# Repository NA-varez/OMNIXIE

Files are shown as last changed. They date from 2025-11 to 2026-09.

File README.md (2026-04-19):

# OMNIXIE
Nixie driver board to enable easy inclusion of a Nixie tube into projects. One common driver board to support a wide range of Nixie INdicator Tubes. I love modularity!

Initial sketches, ideas, original project intent was just a nixie clock. But I hated the feeling of desigingn a nixie clock with the nixie driver circuitry as single use for just a clock, when really you should be able to drive a nixie tube anywehere you'd like for displaying numbers. So that's where this inspiration came from

ALSO cnlohr's cnixxie. Particularly his MCU of choice ch32v003 and the accompanying library ch32v003fun and rv003usb inspired the digitally controlled flyback he uses in his design. Really in hopes of learning some skills he demonstrated in his youtube vide.

OMNIXIE is omni beause all of its OMNIXIE_HATs share a common hardware interface to the nixie driver board. Since nixie tubes wildly vary in their footprint, its nice to share a common hardware connection between them all thats what makes it omni. 

The real guts is the ddriver board.
Should be minimal in size such that it doesnt add any more difficult in creating some case for the nixie tube.
Should be relatively efficient like 90% efficiency on the flyback onverter
Should be programmable 
  There should be a software package that comes with the hardware that could easily spin up different functionality

The default program should allow the user of the board to immediatly get the devices to display a synchronized clock.
Via some qwiic connectors. Might have to be a custom i2c interface.

A flyback seemed to be the most suitable approach because of the smallest amount of parts needed for it.

WORK IN PROGRESS.

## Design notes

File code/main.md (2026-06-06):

//
// cnixi - ch32v003 base driver for IN-15 nixie tubes.
//
// Fully integrated PI flyback PSU controller + Nixie Tube output
// control with up to 2 channel simultaneous dimming.
//
// Copyright 2023 <>< Charles Lohr, under the MIT-X11 license or NewBSD
// license, you choose.
//
// Note: Before running this, you should run the optionbytes folder script
// in order configure RESET as a GPIO so you can use the AUX input as well
// as forcing the watchdog on by default. 
//

#define SYSTEM_CORE_CLOCK 48000000

#include "ch32v003fun.h"
#include <stdio.h>

static uint16_t GenOnMask( int segmenton );
static void ApplyOnMask( uint16_t onmask );
static inline void WatchdogPet();

// Limits the "ADC Set Value" in volts.
// This prevents us from exceeding 190 volts target.
#define ABSOLUTE_MAX_ADC_SET 190

// Do not mess with PWM_ values unless you know what you are willing to go down
// a very deep rabbit hole. I experimentally determined 140 for this particular
// system was on the more efficient side of things and gave good dynamic range.
// 140 means it's 48MHz / 140 = 342 kHz for the main flyback frequency.
//
// You can explore values by doing ENABLE_TUNING in here and in testnix.c
// #define ENABLE_TUNING
#ifndef ENABLE_TUNING
#define PWM_PERIOD 140
#else
int PWM_PERIOD = 140;
#endif
int pwm_max_duty = 48;  //This is changed based on vdd.

// Flyback PID loop Tuning Parameters
//
// This is a PID loop (you should read about this separately). But these terms
// are actually on the order of 2^term. So we are only able to get the tuning
// to a rough ballpark. Thankfully, PID loops are forgiving.
//
// Honestly, this is MUCH more sophisticated than it needs to be!  I was using
// a P-only loop for quite some time without any issues.
#define ERROR_P_TERM 2  // Actually 2^2
#define ERROR_D_TERM -1  // Actually 2^0
#define I_SAT_MAX (4096+2048) // SAT * 2^(-ADC_IIR+ERROR_I_TERM) = Max impact to PWM
#define I_SAT_MIN (-4096)
#define ERROR_I_TERM -5 // Actually 2^-6

// We filter our ADC inputs because they are kind of noisy.
//
// We can use Binary-shift IIR filters to filter the incoming ADC signals.
// See later in the code, but, it maps to only about 4 assembly instructions!
// (plus a read-back of the previous value we will be mixing).
#define ADC_IIR 2
#define VDD_IIR 2

// Target feedback, set by the user.
int target_feedback = 0;

// Feedback based on what the user set and the part's VDD.
int feedback_vdd = 0;

// Filtered ADC and VDD values.
int lastadc = 0;
int lastrefvdd = 0;

// Code for handling numeric fading, between 2 numbers or alone.

uint16_t fade_time0, fade_time1;
uint16_t fade_disp0, fade_disp1;

static uint32_t HandleFade( uint8_t fadepos )  __attribute__((section(".srodata")));
static uint32_t HandleFade( uint8_t fadepos )
{
	// Digit fade.  Use fade_timeX and fade_dispX to handle fade logic.
	if( fadepos < fade_time0 )
		return fade_disp0;
	else if( fadepos < fade_time1 ) 
		return fade_disp1;
	else
		return 0;
}

static inline uint32_t FastMultiply( uint32_t big_num, uint32_t small_num );
static inline uint32_t FastMultiply( uint32_t big_num, uint32_t small_num )
{
	// The CH32V003 is an EC core, so no hardware multiply. GCC's way multiply
	// is slow, so I wrote this.
	//
	// This basically does this:
	//	return small_num * big_num;
	//
	// Note: This does NOT check for zero to begin with, though this still
	// produces the correct results, it is a little weird that even if
	// small_num is zero it executes once.
	//
	// Additionally note, instead of the if( m&1 ) you can do the following:
	//  ret += multiplciant & neg(multiplicand & 1).
	//
	// BUT! Shockingly! That is slower than an extra branch! The CH32V003
	//  can branch unbelievably fast.
	//
	// This is functionally equivelent and much faster.
	//
	// Perf numbers, with small_num set to 180V.
	//  No multiply:         21.3% CPU Usage
	//  Assembly below:      42.4% CPU Usage  (1608 bytes for whole program)
	//  C version:           41.4% CPU Usage  (1600 bytes for whole program)
	//  Using GCC (__mulsi3) 65.4% CPU Usage  (1652 bytes for whole program)
	//
	// The multiply can be done manually:
	uint32_t ret = 0;
	uint32_t multiplicand = small_num;
	uint32_t mutliplicant = big_num;
	do
	{
		if( multiplicand & 1 )
			ret += mutliplicant;
		mutliplicant<<=1;
		multiplicand>>=1;
	} while( multiplicand );
	return ret;

	// Which is equivelent to the following assembly (If you were curious)
/*
	uint32_t ret = 0;
	asm volatile( "\n\
		.option   rvc;\n\
	1:	andi t0, %[small], 1\n\
		beqz t0, 2f\n\
		add %[ret], %[ret], %[big]\n\
	2:	srli %[small], %[small], 1\n\
		slli %[big], %[big], 1\n\
		bnez %[small], 1b\n\
	" :
		[ret]"=&r"(ret), [big]"+&r"(big_num), [small]"+&r"(small_num) : :
		"t0" );
	return ret;
*/
}

// FYI You can use functions in ram to make them work faster.  The .srodata
// attribute. This means this function gets placed into RAM. Normally this
// function takes approximately 2.5-3us to execute from flash, but only 2-2.5us
// to execute from RAM.

// This is an interrupt called by an ADC conversion.
void ADC1_IRQHandler(void)
	__attribute__((interrupt))
	__attribute__((section(".srodata")));

void ADC1_IRQHandler(void)
{
	// If you want to see how long this functon takes to run, you can use a
	// scope and then monitor pin D6 if you uncomment this and the bottom copy.
	GPIOD->BSHR = 1<<6;

	// Acknowledge pending interrupts.
	// This will always be ADC_JEOC, so we don't need to check.
	ADC1->STATR = 0;

	// Acknowledge the interrupt.
	
	// It is crucial that our ADC sample is ALWAYS ALIGNED to the PWM, that way
	// any ripple and craziness that happens from the chopping of the flyback
	// is completely filtered out because of where we are sampling.

	// This performs a low-pass filter on our data, ADC1->RDATAR the sample
	// rate, always.  As a side note, the value of the IIR (but now it's
	// 2^VDD_IIR bigger)

	int adcraw = ADC1->RDATAR;
	int newadc = adcraw + (lastadc - (lastadc>>ADC_IIR));
	lastadc = newadc;

	int err = feedback_vdd - lastadc;

	static int integral;
	static int lasterr;
	int derivative = (err - lasterr);
	lasterr = err;
	integral += err;

	// We asymmetrically allow the integral to saturate, to help prevent long-
	// term oscillations.
	integral = ( integral > ((I_SAT_MAX)<<ADC_IIR) ) ? ((I_SAT_MAX)<<ADC_IIR) : integral;
	integral = ( integral < ((I_SAT_MIN)<<ADC_IIR) ) ? ((I_SAT_MIN)<<ADC_IIR) : integral;

	// This is the heart of the PID loop.
	// General note about shifting: Be sure to combine your shifts.
	// If you shift right, then left, you will lose bits of precision.
	// These shifts turn into single left and right immediate shifts.
	int plant = 
		(err << ( (-ADC_IIR) + (ERROR_P_TERM) )) +
		(integral >> ( ADC_IIR - (ERROR_I_TERM) )) +
		(derivative >> ( (ADC_IIR) - (ERROR_D_TERM) ) );
	plant = ( plant > pwm_max_duty ) ? pwm_max_duty : plant;
	plant = ( plant < 0 ) ? 0 : plant;
	TIM1->CH2CVR = plant;

	// Use injection channel data to read vref.  This is needed because we
	// measure all values WRT to VDD and GND.  So we need to measure the vref
	// a lot to make sure we know what value we are are targeting Ballparks
	//   (for unfiltered numbers)  (Just as a note)
	//   0xF0  / 240 for 5V input << lastrefvdd
	//	 0x175 / 373 for 3.3v input << lastrefvdd

	// Do an IIR low-pass filter on VDD. See IIR discussion above.
	uint32_t vdd = lastrefvdd = ADC1->IDATAR1 + (lastrefvdd - (lastrefvdd>>VDD_IIR));

#ifndef ENABLE_TUNING

	// If we aren't enabling tuning, we can update max on time here. We want to
	// limit on-time based on DC voltage on the flyback so that we can get
	// close to (But not get into) saturation of the flyback transformer's core
	//
	// We can compute expected values, but experimenting is better.
	// Transformer inductance is ~6uH.
	// Our peak current is ~500mA
	// The average voltage is ~4V
	//
	//   4V / .000006H = 0.5A / 666666A/s = 750nS but turns out this was
	//    pessemistic.
	//
	// Experimentation showed that the core of the transformer saturates in
	// about 1uS at 5V and 1.4uS at 3.3v.  More specifically the relationhip
	// between our maximum on-time and vref-measured-by-vdd works out to about:
	//
	//    max_on_time_slices = lastrefvdd / 4.44.
	//
	// There's a neat trick where you can divide by weird decimal divisors by
	// adding and subtracing terms. We perform this trick here and below
	//
	// 1÷(1÷4−1÷64−1÷128−1÷1024) is about equal to dividing by 4.43290
	//  It can be simplified it for our purposes as: 1÷(1÷4−1÷64−1÷128)
	//
	// You can arbitrarily add and subtract terms to get as closed to your
	// desired target value as possbile.
	//
	// When we divide a value by powers-of-two, it becomes a bit shift.
	//
	// The bit shift and IIR adjustments can be made so that the compiler can
	// optimize out the addition there.
	//
	// The following code actually
	pwm_max_duty = 
		  (lastrefvdd>>(2+VDD_IIR)) 
		- (lastrefvdd>>(6+VDD_IIR))
		- (lastrefvdd>>(7+VDD_IIR));
#endif

	// target_feedback is in volts. 0..200 maps to the device voltage.
	// lastrefvdd = 0xF0  for 5V input.
	// lastrefvdd = 0x175 for 3.3v input.
	//
	// feedback_vdd = 408 for ~192V @ 5
	// feedback_vdd = 680 for ~192V @ 3.3
	//
	// 408 = 192 * 240 / x = (192*240)/408 = 112.941176471
	// 680 = 192 * 373 / x = (373*680)/192 = 105.317647059
	//
	//  More tests showed this value across units is around 120.
	//
	// X This becomes our denominator.
	// feedback_vdd = (current vdd measurement * target voltage) / 120
	// 
	// Further testing identified that the denominator is almost exactly 120.
	// We can perform a divison by 120 very quickly by
	//
	//   feedback = numerator/128 + numerator/2048
	//
	// See note above about the constant division trick.
	//
	// Side-note:
	//
	// This is unintuitively slow becuase is because it uses a multiply. The
	// CH32V003 does not natively have a multiply instruction, If you use a *
	// it calls out to __mulsi3 in libgcc.a. 

	// The following line of code is still *more* than fast enough but, to
	// write it out manually, we can get even faster!
	//
	//	uint32_t numerator = (vdd * target_feedback);

	uint32_t numerator = FastMultiply( vdd, target_feedback );

	feedback_vdd =
		(numerator>>(7+VDD_IIR-ADC_IIR)) +
		(numerator>>(11+VDD_IIR-ADC_IIR));

	// Pet the watchdog.  If we got here, things should be OK.
	WatchdogPet();

	GPIOD->BSHR = (1<<(16+6));
}

static void SetupTimer1()
{
	// Enable Timer 1
	RCC->APB2PRSTR |= RCC_APB2Periph_TIM1;
	RCC->APB2PRSTR &= ~RCC_APB2Periph_TIM1;

	TIM1->PSC = 0x0000;  // Prescalar to 0x0000 (so, 48MHz base clock)
	TIM1->ATRLR = PWM_PERIOD;
	TIM1->CCER = TIM_CC2E | TIM_CC2NP;  // CH2 is control for FET.
	TIM1->CHCTLR1 = TIM_OC2M_2 | TIM_OC2M_1;

	TIM1->CH2CVR = 0;  // Actual duty cycle (Off to begin with)

	// Setup TRGO for ADC.  This makes is to the ADC will trigger on timer
	// reset, so we trigger at the same position every time relative to the
	// FET turning on.
	TIM1->CTLR2 = TIM_MMS_1;

	// Enable TIM1 outputs
	TIM1->BDTR = TIM_MOE;
	TIM1->CTLR1 = TIM_CEN;
}

static void SetupTimer2()
{
	// Enable Timer 2
	RCC->APB1PRSTR |= RCC_APB1Periph_TIM2;
	RCC->APB1PRSTR &= ~RCC_APB1Periph_TIM2;

	// PD7 will be used as Timer 2, Channel 4 Configure timer 2 to enable this.
	//TIM2->SWEVGR = 0x0001; 			//TIM_PSCReloadMode_Immediate;

	TIM2->PSC = 0x0020;
	TIM2->ATRLR = 255;				// 0..255 (So we can be 100% on)
	TIM2->CHCTLR2 = TIM_OC4M_2 | TIM_OC4M_1;
	TIM2->CCER = TIM_CC4E;
	TIM2->CH4CVR = 0;  			// Actual duty cycle (Off to begin with)

	// Enable TIM1 outputs
	TIM2->BDTR = TIM_MOE;
	TIM2->CTLR1 = TIM_CEN;
}

static void SetupADC()
{
	// Configure ADC.
	// PD4 is analog input chl 7
	GPIOD->CFGLR &= ~(0xf<<(4*4));	// CNF = 00: Analog, MODE = 00: Input
	
	// Reset the ADC to init all regs
	RCC->APB2PRSTR |= RCC_APB2Periph_ADC1;
	RCC->APB2PRSTR &= ~RCC_APB2Periph_ADC1;

	// ADCCLK = 12 MHz => RCC_ADCPRE divide by 4
	RCC->CFGR0 &= ~RCC_ADCPRE;  // Clear out the bis in case they were set
	RCC->CFGR0 |= RCC_ADCPRE_DIV4;	// set it to 010xx for /4.

	// Set up single conversion on chl 7
	ADC1->RSQR1 = 0;
	ADC1->RSQR2 = 0;
	ADC1->RSQR3 = 7;	// 0-9 for 8 ext inputs and two internals
	
	//Injection group is 8. NOTE: See note in 9.3.12 (ADC_ISQR) of TRM. The
	// group numbers is actually 4-group numbers.
	ADC1->ISQR = (8<<15) | (0<<20);

	// Sampling time for channels. Careful: This has PID tuning implications.
	// Note that with 3 and 3,the full loop (and injection) runs at 138kHz.
	ADC1->SAMPTR2 = (3<<(3*7)) | (3<<(3*8)); 
		// 0:7 => 3/9/15/30/43/57/73/241 cycles
		// (4 == 43 cycles), (6 = 73 cycles)  Note these are alrady /2, so 
		// setting this to 73 cycles actually makes it wait 256 total cycles
		// @ 48MHz.

	// Turn on ADC and set rule group to sw trig
	// 0 = Use TRGO event for Timer 1 to fire ADC rule.
	ADC1->CTLR2 = ADC_ADON | ADC_JEXTTRIG | ADC_JEXTSEL | ADC_EXTTRIG; 

	// Reset calibration
	ADC1->CTLR2 |= ADC_RSTCAL;
	while(ADC1->CTLR2 & ADC_RSTCAL);

	// Calibrate ADC
	ADC1->CTLR2 |= ADC_CAL;
	while(ADC1->CTLR2 & ADC_CAL);

	// enable the ADC Conversion Complete IRQ
	NVIC_EnableIRQ( ADC_IRQn );

	// ADC_JEOCIE: Enable the End-of-conversion interrupt.
	// ADC_JDISCEN | ADC_JAUTO: Force injection after rule conversion.
	// ADC_SCAN: Allow scanning.
	ADC1->CTLR1 = ADC_JEOCIE | ADC_JDISCEN | ADC_SCAN | ADC_JAUTO;
}

// Apply a given output mask to the GPIO ports the nixie tubes are hooked into.
static void ApplyOnMask( uint16_t onmask )
{
	GPIOD->OUTDR = (onmask >> 8) | 0x80;
	GPIOC->OUTDR = onmask & 0xff;
}

uint16_t GenOnMask( int segmenton )
{
	// Produce a bit mask with only one bit on. To indicate the IO to turn on
	// to light up a given segment.  If segmenton == 0, then all IO are off.
	if( segmenton > 0 )
	{
		segmenton--;
		if( segmenton < 8 )
			return 1<<segmenton;
		else if( segmenton == 8 )
			return (1<<2)<<8;
		else if( segmenton == 9 )
			return (1<<3)<<8;
		else if( segmenton == 10 )
			return (1<<0)<<8;
		else if( segmenton == 11 )
			return (1<<7)<<8;
	}
	return 0;
}

static void HandleCommand( uint32_t dmdword )
{
	// You can use minichlink to setup this:
	// ./minichlink -s 0x04 0x00B40041 # Configure for 180V.
	// ./minichlink -s 0x04 0x00030042 # Light digit "8"
	// ./minichlink -s 0x04 0x60303243 # Dimly light 8 and 8.
	// ./minichlink -g 0x04            # Get status.

	// Note: To get here, DEBUG0's LSB must be 0x4x command is that 'x'
	int command = dmdword & 0x0f;

	switch( command )
	{
	case 1:
	{
		int feedback = dmdword >> 16;
		if( feedback > ABSOLUTE_MAX_ADC_SET )
			feedback = ABSOLUTE_MAX_ADC_SET;
		target_feedback = feedback;
		break;
	}
	case 2:
	{
		int segmenton = (dmdword>>16)&0x0f;

		fade_time0 = -1;
		fade_time1 = -1;
		fade_disp0 = GenOnMask(segmenton);
		fade_disp1 = 0;
		break;
	}
	case 3:
	{
		// Configure a fade.
		fade_disp0 = GenOnMask( ( dmdword >> 8 ) & 0xf );
		fade_disp1 = GenOnMask( ( dmdword >> 12 ) & 0xf );
		fade_time0 = ( dmdword >> 16 ) & 0xff;
		fade_time1 = ( dmdword >> 24 ) & 0xff;
		break;
	}
	case 4:
	{
#ifdef ENABLE_TUNING
		// this is only for tuning.
		if( ( dmdword & 0xff00 ) == 0xaa00 )
		{
			int period = (dmdword>>16)&0xff;
			if( period < 20 ) period = 20;
			PWM_PERIOD = period;
			TIM1->ATRLR = PWM_PERIOD;
			int max_duty = (dmdword>>24)&0xff;
			if( max_duty > period - 14 ) max_duty = period - 14;
			pwm_max_duty = max_duty;
		}
#endif
		break;
	}
	case 5:
	{
		// Aux Neon Control
		TIM2->CH4CVR = dmdword>>16;
	}

	}

	// Write the status back to the host PC.  Status is our VDD and our FB V
	*DMDATA0 = ((lastadc>>ADC_IIR) << 12) | ((lastrefvdd>>VDD_IIR) << 22);
}

static inline void WatchdogPet()
{
	// Writing 0xaaaa into the ctlr prevents the watchdog from killing us.
	IWDG->CTLR = 0xAAAA;
}

static inline void WatchdogSetup()
{
	// Setup watchdog.
	IWDG->CTLR = 0x5555; // Go into watchdog setup mode.
	while( IWDG->STATR & IWDG_PVU ); // Wait for PSCR to become recepitve.
	IWDG->PSCR = 1;      // div LSI by 8 (4 seems unreliable)
	IWDG->RLDR = 0xFFF;  // reload watchdog, not important don't need to check.
	IWDG->CTLR = 0xCCCC; // commit registers.
	WatchdogPet();
}

static inline void AdvanceFadePlace()
{
	static uint32_t lastmask = 0;

	// Causes us to cycle through all 256 sequence points every 1.5ms.
	uint32_t fadepos = (SysTick->CNT >> 5) & 0xff;

	// We want to glow the LEDs with a chopping period of less, so we
	// "rotate" the bits.  This has the effect of making the primary
	// switching frequency for the tubes much higher, but, at the same time
	// also jittering the edges in time so you can get a full 8-bit fade.
	// You can rotate more or less to control the periodicity.

	// With this scramble, the period scramble is about 93us.
	fadepos = (fadepos << 4) | ( fadepos >> 4);

	uint32_t mask = HandleFade( fadepos );
	if( mask != lastmask )
	{
		if( lastmask )
		{
			// Make sure we have a short gap with nothing on.
			ApplyOnMask( 0 );
			Delay_Us( 3 );
		}
		ApplyOnMask( mask );
		lastmask = mask;
	}
}

int main()
{
	// Configure a watchdog timer so if the chip goes crazy it will reset.
	WatchdogSetup();

	// Use internall RC oscillator + 2xPLL to generate 48 MHz system clock.
	SystemInit(); /// ********************************************

	// For the ability to printf() if we want.
	SetupDebugPrintf();

	// Pet watchdog for the rest of startup.
	WatchdogPet();

	// Enable Peripherals
	RCC->APB2PCENR |= RCC_APB2Periph_GPIOD | RCC_APB2Periph_GPIOC |
		RCC_APB2Periph_GPIOA | RCC_APB2Periph_TIM1 | RCC_APB2Periph_ADC1 |
		RCC_APB2Periph_AFIO;

	RCC->APB1PCENR = RCC_APB1Periph_TIM2;

	// I'm paranoid - let's make sure all tube cathodes are high-Z.
	ApplyOnMask( 0 );

	GPIOD->CFGLR = 
		(GPIO_Speed_10MHz | GPIO_CNF_OUT_PP)<<(4*6) | // GPIO D6 Debug
		(GPIO_Speed_10MHz | GPIO_CNF_OUT_PP_AF)<<(4*7) | // DIG_AUX  (TIM2CH4)
		(GPIO_Speed_10MHz | GPIO_CNF_OUT_PP)<<(4*3) | // DIG_9
		(GPIO_Speed_10MHz | GPIO_CNF_OUT_PP)<<(4*2) | // DIG_8
		(GPIO_Speed_10MHz | GPIO_CNF_IN_FLOATING)<<(4*1) | // PGM Floats.
		(GPIO_Speed_10MHz | GPIO_CNF_OUT_PP)<<(4*0);  // DIG_DOT

	GPIOC->CFGLR = 
		(GPIO_Speed_10MHz | GPIO_CNF_OUT_PP)<<(4*0) | // DIG_0
		(GPIO_Speed_10MHz | GPIO_CNF_OUT_PP)<<(4*1) | // DIG_1
		(GPIO_Speed_10MHz | GPIO_CNF_OUT_PP)<<(4*2) | // DIG_2
		(GPIO_Speed_10MHz | GPIO_CNF_OUT_PP)<<(4*3) | // DIG_3
		(GPIO_Speed_10MHz | GPIO_CNF_OUT_PP)<<(4*4) | // DIG_4
		(GPIO_Speed_10MHz | GPIO_CNF_OUT_PP)<<(4*5) | // DIG_5
		(GPIO_Speed_10MHz | GPIO_CNF_OUT_PP)<<(4*6) | // DIG_6
		(GPIO_Speed_10MHz | GPIO_CNF_OUT_PP)<<(4*7);  // DIG_7

	GPIOA->CFGLR =
		(GPIO_Speed_50MHz | GPIO_CNF_OUT_PP_AF)<<(4*1); //FLYBACK (T1CH2)

	SetupADC();
	SetupTimer1();
	SetupTimer2();

	*DMDATA0 = 0;

	target_feedback = 0;

	// Cause system timer to run and reload when it hits CMP and HCLK/8.
	// Also, don't stop at comparison value.
	SysTick->CTLR = 1;

	while(1)
	{
		uint32_t dmdword = *DMDATA0;
		if( (dmdword & 0xf0) == 0x40 )
		{
			// I think there is a compiler bug here.  For some reason if I put
			// the code in this function right here, it doesn't work right.
			// so I encapsulated the code in a function.
			//
			// This function handles commands we get over the programming
			// interface.  Like "set HV bus" or "set this digit on."
			HandleCommand( dmdword );
		}

		AdvanceFadePlace();

	}
}

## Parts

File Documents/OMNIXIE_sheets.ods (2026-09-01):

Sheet: PROTOTYPE BOM v0.1
 |  | BOM | 1 | OMNIXIE
 |  | SCH | 1
 |  | PCB | 1 | Designer: NA Design
 |  | DATE | 12/26/2025
PROCURED | TO BUY | Categories | Qty | MPN | Ref Des | Value | DNP | Description | Footprint/Package | Manufacturer | Distributor | Link
TRUE | TRUE | ICs/Modules | 1 | CH32V003F4U6 | U1 | - |  | QingKe V2 Microprocessor | Package_DFN_QFN:QFN-20-1EP_3x3mm_P0.4mm_EP1.65x1.65mm
TRUE | TRUE |  | 1 | PI4IOE5V6416ZDEX | U3 | - |  | I/O Expander 16 I2C 400 kHz 24-TQFN (4x4) | Package_DFN_QFN:TQFN-24-1EP_4x4mm_P0.5mm_EP2.1x2.1mm_ThermalVias
TRUE | TRUE |  | 1 | XC6206P332MR | U4 | - |  | IC REG LINEAR 3.3V 200MA SOT23 | Package_TO_SOT_SMD:SOT-23-3
TRUE | TRUE | Connections | 1 | USB4120-03-C | J4 | - |  | USB Connectors USB Type C,2.0, Rec,SMT, 0.95mmTH Shell Stakes,G/F,RA,Top Mnt,T&R
TRUE | FALSE |  | 2 | - | J1,J6 | - |  | 2.54mm Pitch Pin Headers
TRUE | TRUE |  | 7 | 5005 | TP6,TP8,TP10,TP11,TP12,TP13,TP14 | - |  | Test Plugs & Test Jacks TEST POINT RED .063 | TestPoint:TestPoint_Keystone_5005-5009_Compact
TRUE | TRUE |  | 1 | IL-WX-16S-VF-B-E1000E | J8 | - |  | 0.8 mm pitch, SMT, parallel/ vertical, Board-to-board Connector, 16 pos., Socket receptacle
TRUE | TRUE | Semiconductors | 1 | IPN50R1K4CEATMA1 | Q12 | - |  | MOSFETs CONSUMER | Package_TO_SOT_SMD:SOT-223-3_TabPin2
TRUE | TRUE |  | 12 | BSS123 | Q0,Q1,Q2,Q3,Q4,Q5,Q6,Q7,Q8,Q9,Q10,Q11 | - |  | MOSFET, N-CH, SINGLE, 0.19A, 100 | Package_TO_SOT_SMD:SOT-23-3
TRUE | TRUE |  | 1 | SK3200AFL-TP | D1 | - |  | Schottky Diodes & Rectifiers 3A 200Vr 140Vrms 200V 80A 0.86Vf | OMNIXIE:SK3200AFL
TRUE | TRUE |  | 2 | 150060GS73220 | D2, D3 | - |  | Green 525nm LED Indication - Discrete 3.2V 0603 (1608 Metric) | LED_SMD:LED_0603_1608Metric
TRUE | FALSE | Capacitors/Resistors | 1 | GRM21BR71A106MA73K | C1 | 10uF |  | Multilayer Ceramic Capacitors MLCC - SMD/SMT 10 uF 10 VDC 20% 0805 X7R | _0805
TRUE | TRUE |  | 1 | GRM43DR7LV224KW01L | C2 | 0.22uF |  | Multilayer Ceramic Capacitors MLCC - SMD/SMT 0.22 uF 630 VDC 10% 1812 X7R | 1210
TRUE | FALSE |  | 3 | CL10B105KA8NFNC | C3, C4, C5 | 1uF |  | 1 µF ±10% 25V Ceramic Capacitor X7R 0603 (1608 Metric) | _0805
TRUE | TRUE |  | 2 | PA0603FRE570R01L | R3,R5 | 10m |  | 10 mOhms ±1% 0.5W, 1/2W Chip Resistor 0603 (1608 Metric) Automotive AEC-Q200, Current Sense, Moisture Resistant Metal Element | _0603
FALSE | FALSE |  | 2 | - | R10,R16 | 10k |  | - | _0805
TRUE | TRUE |  | 1 | RC2010JK-0715KL | R6 | 15k |  | Thick Film Resistors - SMD General Purpose Chip Resistor 2010, 15kOhms, 5%, 3/4W | 2010
TRUE | FALSE |  | 1 | RC0402FR-07100KL | R7 | 100k |  | 100 kOhms ±1% 0.063W, 1/16W Chip Resistor 0402 (1005 Metric) Moisture Resistant Thick Film | _0805
TRUE | FALSE |  | 2 | 560112110017 | R8,R9 | 47 |  | Thick Film Resistors - SMD WRIS-RSKS 47 Ohms 5 % 0.1 W 0402 AEC-Q200 | _0805
TRUE | FALSE |  | 2 | RK73H1JTTD1001F | R11,R12 | 1k |  | 1 kOhms ±1% 0.125W, 1/8W Chip Resistor 0603 (1608 Metric) Automotive AEC-Q200 Thick Film | _0805
TRUE | FALSE |  | 2 | CR0603-FX-5101ELF | R13,R14 | 5.1k |  | Thick Film Resistors - SMD 5.1K ohm 1% | _0805
TRUE | FALSE |  | 1 | CRCW04021K50JNEDC | R15 | 1.5k |  | Thick Film Resistors - SMD 1/16watt 1.5Kohms 5% Commercial Use | _0805
TRUE | TRUE | Other | 1 | ATB322515-0110 | T1 | - |  | Audio Transformers / Signal Transformers Photoflash Capacitor Charging Transforme
FALSE | FALSE
TRUE | TRUE | For Later Use | 2 | BM03B-SRSS-TB
TRUE | TRUE |  | 2 | SM04B-SRSS-TB | J2, J3 | - |  | Connector Header Surface Mount, Right Angle 4 position 0.039" (1.00mm)
TRUE | TRUE |  | 1 | IL-WX-16PB-VF-B-E1000E |  | - |  | 0.8 mm pitch, SMT, parallel/ vertical, Board-to-board Connector, 16 pos., Pin header
 |  |  |  | RK0971114D0B | potentiometer

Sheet: PROTOTYPE BOM v0.2
 |  | BOM | 1 | OMNIXIE
 |  | SCH | 1
 |  | PCB | 1 | Designer: NA Design
 |  | DATE | 8/9/2026
PROCURED | TO BUY | Categories | Qty | MPN | Ref Des | Value | DNP | Description | Footprint/Package | Manufacturer | Distributor | Link
TRUE | FALSE | ICs/Modules | 1 | CH32V003F4U6 | U1 | - |  | QingKe V2 Microprocessor | Package_DFN_QFN:QFN-20-1EP_3x3mm_P0.4mm_EP1.65x1.65mm
TRUE | FALSE |  | 1 | PI4IOE5V6416ZDEX | U3 | - |  | I/O Expander 16 I2C 400 kHz 24-TQFN (4x4) | Package_DFN_QFN:TQFN-24-1EP_4x4mm_P0.5mm_EP2.1x2.1mm_ThermalVias
TRUE | FALSE |  | 1 | XC6206P332MR | U4 | - |  | IC REG LINEAR 3.3V 200MA SOT23 | Package_TO_SOT_SMD:SOT-23-3
TRUE | FALSE | Connections | 1 | USB4105-GF-A | J4 | - |  | USB-C (USB TYPE-C) USB 2.0 Receptacle Connector 24 (16+8 Dummy) Position Surface Mount, Right Angle; Through Hole
TRUE | FALSE |  | 2 | - | J1,J6 | - |  | 2.54mm Pitch Pin Headers
TRUE | FALSE |  | 7 | 5005 | TP6,TP8,TP10,TP11,TP12,TP13,TP14 | - |  | Test Plugs & Test Jacks TEST POINT RED .063 | TestPoint:TestPoint_Keystone_5005-5009_Compact
TRUE | FALSE |  | 1 | IL-WX-16S-VF-B-E1000E | J8 | - |  | 0.8 mm pitch, SMT, parallel/ vertical, Board-to-board Connector, 16 pos., Socket receptacle
TRUE | FALSE | Semiconductors | 1 | STN1NK60ZL | Q12 | - |  | MOSFET N-CH 600V 300MA SOT223 | SOT-223
TRUE | FALSE |  | 12 | BSS123 | Q0,Q1,Q2,Q3,Q4,Q5,Q6,Q7,Q8,Q9,Q10,Q11 | - |  | MOSFET, N-CH, SINGLE, 0.19A, 100 | Package_TO_SOT_SMD:SOT-23-3
TRUE | FALSE |  | 1 | SK3200AFL-TP | D1 | - |  | Schottky Diodes & Rectifiers 3A 200Vr 140Vrms 200V 80A 0.86Vf | OMNIXIE:SK3200AFL
TRUE | FALSE |  | 2 | 150060GS73220 | D2, D3 | - |  | Green 525nm LED Indication - Discrete 3.2V 0603 (1608 Metric) | LED_SMD:LED_0603_1608Metric
TRUE | FALSE | Capacitors/Resistors | 1 | GRM21BR71A106MA73K | C1 | 10uF |  | Multilayer Ceramic Capacitors MLCC - SMD/SMT 10 uF 10 VDC 20% 0805 X7R | _0805
TRUE | FALSE |  | 1 | GRM43DR7LV224KW01L | C2 | 0.22uF |  | Multilayer Ceramic Capacitors MLCC - SMD/SMT 0.22 uF 630 VDC 10% 1812 X7R | 1210
TRUE | FALSE |  | 3 | CL10B105KA8NFNC | C3, C4, C5 | 1uF |  | 1 µF ±10% 25V Ceramic Capacitor X7R 0603 (1608 Metric) | _0805
TRUE | FALSE |  | 2 | PA0603FRE570R01L | R3,R5 | 10m |  | 10 mOhms ±1% 0.5W, 1/2W Chip Resistor 0603 (1608 Metric) Automotive AEC-Q200, Current Sense, Moisture Resistant Metal Element | _0603
TRUE | FALSE |  | 2 | - | R10,R16 | 30k |  | - | _0805
TRUE | FALSE |  | 1 | RC2010JK-0715KL | R6 | 15k |  | Thick Film Resistors - SMD General Purpose Chip Resistor 2010, 15kOhms, 5%, 3/4W | 2010
TRUE | FALSE |  | 1 | RC0402FR-07100KL | R7 | 100k |  | 100 kOhms ±1% 0.063W, 1/16W Chip Resistor 0402 (1005 Metric) Moisture Resistant Thick Film | _0805
TRUE | FALSE |  | 2 | 560112110017 | R8,R9 | 47 |  | Thick Film Resistors - SMD WRIS-RSKS 47 Ohms 5 % 0.1 W 0402 AEC-Q200 | _0805
TRUE | FALSE |  | 2 | RK73H1JTTD1001F | R11,R12 | 1k |  | 1 kOhms ±1% 0.125W, 1/8W Chip Resistor 0603 (1608 Metric) Automotive AEC-Q200 Thick Film | _0805
TRUE | FALSE |  | 2 | CR0603-FX-5101ELF | R13,R14 | 5.1k |  | Thick Film Resistors - SMD 5.1K ohm 1% | _0805
TRUE | FALSE |  | 1 | CRCW04021K50JNEDC | R15 | 1.5k |  | Thick Film Resistors - SMD 1/16watt 1.5Kohms 5% Commercial Use | _0805
TRUE | FALSE | Other | 1 | ATB322515-0110 | T1 | - |  | Audio Transformers / Signal Transformers Photoflash Capacitor Charging Transforme
TRUE | FALSE
TRUE | FALSE | For Later Use | 2 | BM03B-SRSS-TB
TRUE | FALSE |  | 2 | SM04B-SRSS-TB | J2, J3 | - |  | Connector Header Surface Mount, Right Angle 4 position 0.039" (1.00mm)
TRUE | FALSE |  | 1 | IL-WX-16PB-VF-B-E1000E |  | - |  | 0.8 mm pitch, SMT, parallel/ vertical, Board-to-board Connector, 16 pos., Pin header
TRUE | FALSE | Alternatives | 1 | ZVN4424G | Q12 |  |  | SOT223 N-CHANNEL ENHANCEMENT MODE VERTICAL DMOSFET, 240V | SOT-223
TRUE | FALSE
TRUE | FALSE
 |  |  |  | RK0971114D0B | potentiometer

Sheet: CH32V003F4U6 PIN FUNCTIONS
KEY |  | PIN | PORT | FUNCTIONS |  |  |  |  |  | USB
A: ADC, A7 (ADC_IN7) |  | 1 | PD7 | NRST | T2CH4 | OPP1 | UCK
T: TIME, T2CH4 (TIM2_CH4) |  | 2 | PA1 | OSCI | A1 | T1CH2 | OPN0
U: USART, URX (USART_RX) |  | 3 | PA2 | OSCO | A0 | T1CH2N | OPP0 | AETR2
OP: OPA, OPO (OPA_OUT), OPP1 (OPA_P1) |  | 4 | VSS
OSCI (OSCIN) |  | 5 | PD0 | T1CH1N | OPN1 | SDA | UTX
OSCO (OSCOUT) |  | 6 | VDD
SDA (I2C_SDA) |  | 7 | PC0 | T2CH3 | UTX | NSS | T1CH3
SCL (I2C_SCL) |  | 8 | PC1 | SDA | NSS | T2CH4 | T2CH1ETR | T1BKIN | URX
SCK (SPI_SCK) |  | 9 | PC2 | SCL | URTS | T1BKIN | AETR | T2CH2 | T1ETR
NSS (SPI_NSS) |  | 10 | PC3 | T1CH3 | T1CHIN | UCTS
MOSI (SPI_MOSI) |  | 11 | PC4 | A2 | T1CH4 | MCO | T1CH1CH2N
MISO (SPI_MISO) |  | 12 | PC5 | SCK | T1ETR | T2CH1ETR | SCL | UCK | T1CH3
AETR(ADC_ETR): ADC EXTRA |  | 13 | PC6 | MOSI | T1CH1CH3 | UCTS | SDA
 |  | 14 | PC7 | MISO | T1CH2 | T2CH2 | URTS
 |  | 15 | PD1 | SWIO | AETR | T1CH3 | SCL | URX
 |  | 16 | PD2 | A3 | T1CH1 | T2CH3 | T1CH2N
 |  | 17 | PD3 | A4 | T2CH2 | AETR | UCTS | T1CH4 |  | D+
 |  | 18 | PD4 | A7 | UCK | T2CH1ETR | OPO | T1CH4ETR |  | D-
 |  | 19 | PD5 | A5 | UTX | T2CH4 | URX |  |  | DPU
 |  | 20 | PD6 | A7 | URX | T2CH3 | UTX
 |  |  | https://github.com/cnlohr/rv003usb
 |  |  | https://github.com/cnlohr/ch32fun
 |  |  | https://github.com/cnlohr/cnixxi
 |  |  | https://threeneurons.wordpress.com/nixie-power-supply/
 | USB just requires that D+ D- and DPU are on the same port

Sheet: CNIXXI VS OMNIXIE PINOUT
KEY |  | PIN | PORT | CNIXXI | OMNIXIE | FUNCTIONS |  |  |  |  |  | USB
A: ADC, A7 (ADC_IN7) |  | 1 | PD7 | DIG_AUX | PINNED OUT | NRST | T2CH4 | OPP1 | UCK
T: TIME, T2CH4 (TIM2_CH4) |  | 2 | PA1 | HV_CTL | PINNED OUT | OSCI | A1 | T1CH2 | OPN0
U: USART, URX (USART_RX) |  | 3 | PA2 | FLOATING | PINNED OUT | OSCO | A0 | T1CH2N | OPP0 | AETR2
OP: OPA, OPO (OPA_OUT), OPP1 (OPA_P1) |  | 4 | VSS | GND | GND
OSCI (OSCIN) |  | 5 | PD0 | DIG_DOT | PINNED OUT | T1CH1N | OPN1 | SDA | UTX
OSCO (OSCOUT) |  | 6 | VDD | 5V | 3.3V
SDA (I2C_SDA) |  | 7 | PC0 | DIG_0 | PINNED OUT | T2CH3 | UTX | NSS | T1CH3
SCL (I2C_SCL) |  | 8 | PC1 | DIG_1 | SDA | SDA | NSS | T2CH4 | T2CH1ETR | T1BKIN | URX
SCK (SPI_SCK) |  | 9 | PC2 | DIG_2 | SDL | SCL | URTS | T1BKIN | AETR | T2CH2 | T1ETR
NSS (SPI_NSS) |  | 10 | PC3 | DIG_3 | PC3 | T1CH3 | T1CHIN | UCTS
MOSI (SPI_MOSI) |  | 11 | PC4 | DIG_4 | HV_FEEDBACK | A2 | T1CH4 | MCO | T1CH1CH2N
MISO (SPI_MISO) |  | 12 | PC5 | DIG_5 | PINNED OUT | SCK | T1ETR | T2CH1ETR | SCL | UCK | T1CH3
AETR(ADC_ETR): ADC EXTRA |  | 13 | PC6 | DIG_6 | PINNED OUT | MOSI | T1CH1CH3 | UCTS | SDA
 |  | 14 | PC7 | DIG_7 | HV_SW | MISO | T1CH2 | T2CH2 | URTS
 |  | 15 | PD1 | PGM | PROGRAM | SWIO | AETR | T1CH3 | SCL | URX
 |  | 16 | PD2 | DIG_8 | PINNED OUT | A3 | T1CH1 | T2CH3 | T1CH2N
 |  | 17 | PD3 | DIG_9 | D+ | A4 | T2CH2 | AETR | UCTS | T1CH4 |  | D+
 |  | 18 | PD4 | HVVMON | D- | A7 | UCK | T2CH1ETR | OPO | T1CH4ETR |  | D-
 |  | 19 | PD5 | URX | DPU | A5 | UTX | T2CH4 | URX |  |  | DPU
 |  | 20 | PD6 | UTX | PINNED OUT | A7 | URX | T2CH3 | UTX
 |  |  | https://github.com/cnlohr/rv003usb
 |  |  | https://github.com/cnlohr/ch32fun
 |  |  | https://github.com/cnlohr/cnixxi
 |  |  | https://threeneurons.wordpress.com/nixie-power-supply/
 | USB just requires that D+ D- and DPU are on the same port

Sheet: COST ESTIMATES
 | Stencil | Qty 5 (1.25in x 0.75in) | Shipping | Total Cost
PCBWay | $10.00 | $5.00 | $24.15 | $39.15
JLCPCB | $7.00 | $2.00 | $42.66 | $60.00
OSHPARK | N/A | $7.50
OSHSTENCIL

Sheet: ARCHIVE
12 | BSS131H6327XTSA1 |  |  | MOSFETs N-Ch 240V 100mA SOT-23-3
1 | 500 |  |  | Coin Cell Battery Holders COIN CELL HOLDER 12MM
 | SN75468DR (https://www.lcsc.com/product-detail/C2871134.html?s_z=n_SN75468)
Buy bulk from Adafruit | 3825
 | 10 | GAN190-650FBEZ |  |  | GaN FETs SOT8075 650V 11.5A FET
 |  | https://www.digikey.com/en/products/detail/koa-speer-electronics-inc/RCUCTE/11476561
 |  | 12 | 770004-4 |  |  | Pin & Socket Connectors SOCKET CONTACT
 |  | bulk | Qwiic short cables
 |  | Other Stuff To Buy
 |  | 1 | ATB3225-75011CT-T001 |  |  | Audio Transformers / Signal Transformers 1:1 75ohms 5-200MHz 10dB
 |  | 1 | 78201465351 |  |  | Ferrite Cores & Accessories WE-OEFA LFS Oval Ferrite Core Oval; 25Ohms; 72Ohms Black AEC-Q200
 |  | 2 | RK0971114D0B |  |  | Potentiometers Flat 15mm 10k
 |  | 12 | 02-09-1104 |  |  | Pin & Socket Connectors CRIMP SKT BULK 14-20
 |  | 100 | IN12-A sockets purchased |  |  | https://www.amazon.com/gp/product/B09D2VQR3Q

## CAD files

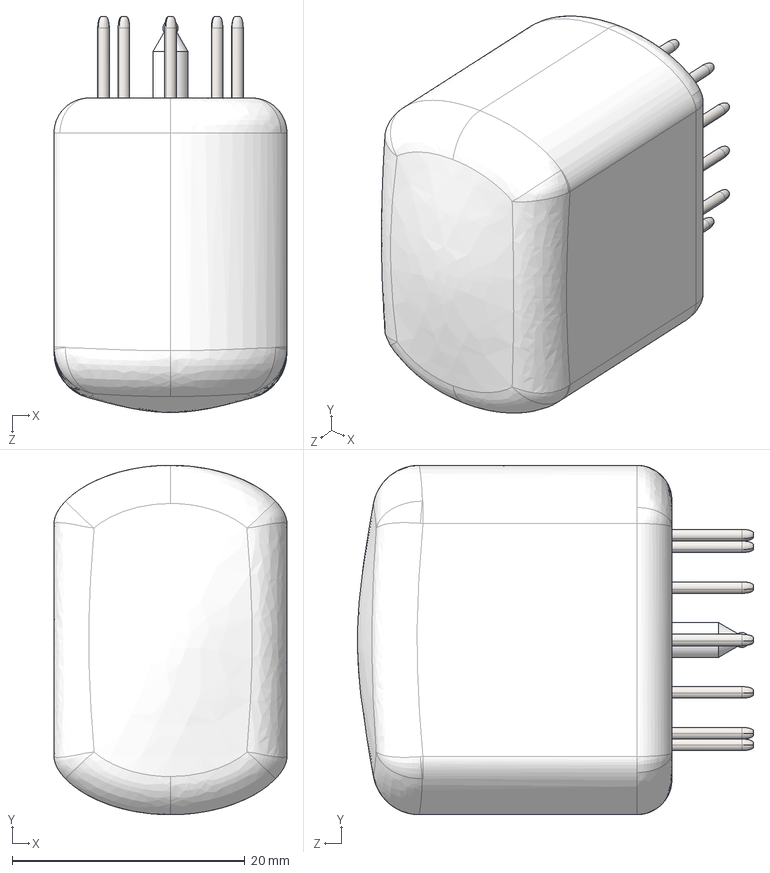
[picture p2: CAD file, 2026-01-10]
kicad_projects/omnixie_v0.2/3DModels/IN-12 Nixie Tube.STEP
20.0 x 30.0 x 34.0 mm
IN-12 nixie tube glass body
IN-12 nixie tube pin x 12
IN-12 nixie tube anode grid
IN-12 nixie tube 0 digit
IN-12 nixie tube 1 digit
IN-12 nixie tube 2 digit
IN-12 nixie tube 3 digit
IN-12 nixie tube 4 digit
IN-12 nixie tube 5 digit
IN-12 nixie tube 6 digit
IN-12 nixie tube 7 digit
IN-12 nixie tube 8 digit
IN-12 nixie tube 9 digit
IN-12 nixie tube spacer x 24
IN-12 nixie tube rod x 2
IN-12 nixie tube back plate 1
IN-12 nixie tube back plate 2

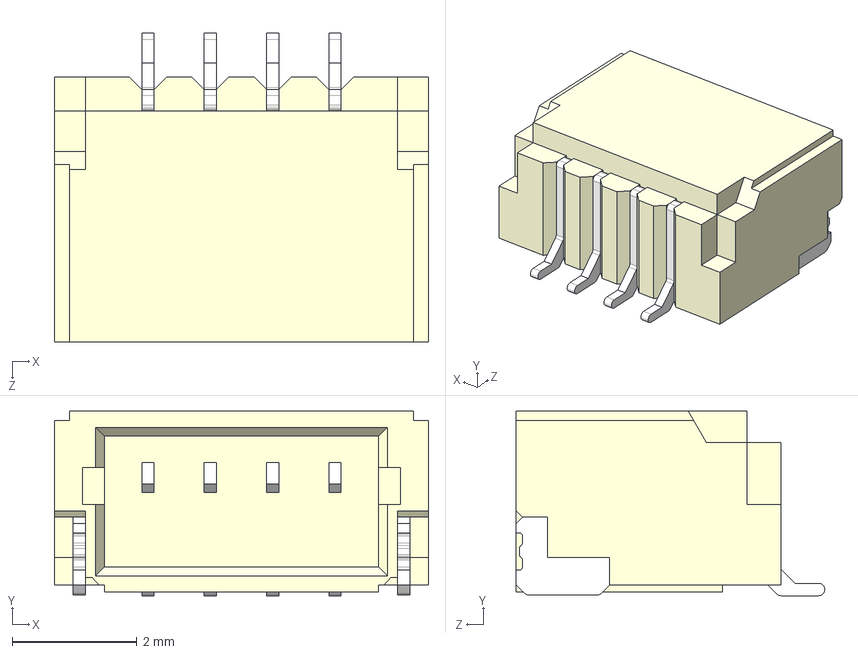
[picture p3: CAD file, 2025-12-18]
kicad_projects/omnixie_v0.2/3DModels/SM04B-SRSS-TB.STEP
6.00 x 2.96 x 4.95 mm

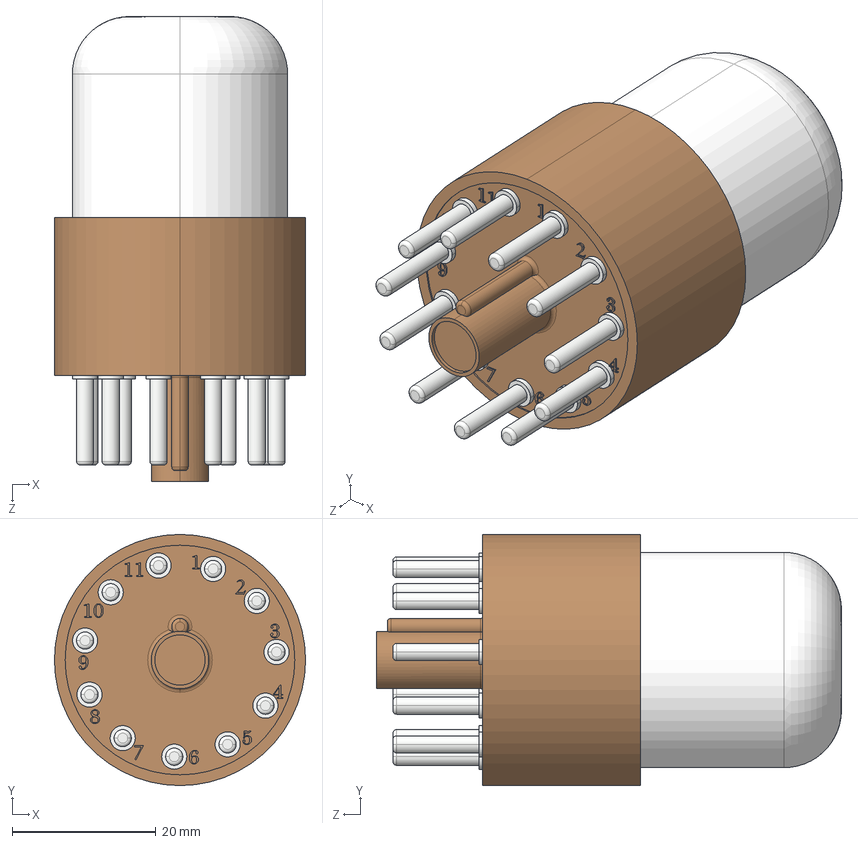
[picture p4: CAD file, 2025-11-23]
kicad_projects/omnixie_v0.2/3DModels/ИН-1.STEP
35.0 x 35.0 x 64.8 mm
ИН-1_Base
ИН-1_Dome
ИН-1_Pin x 11

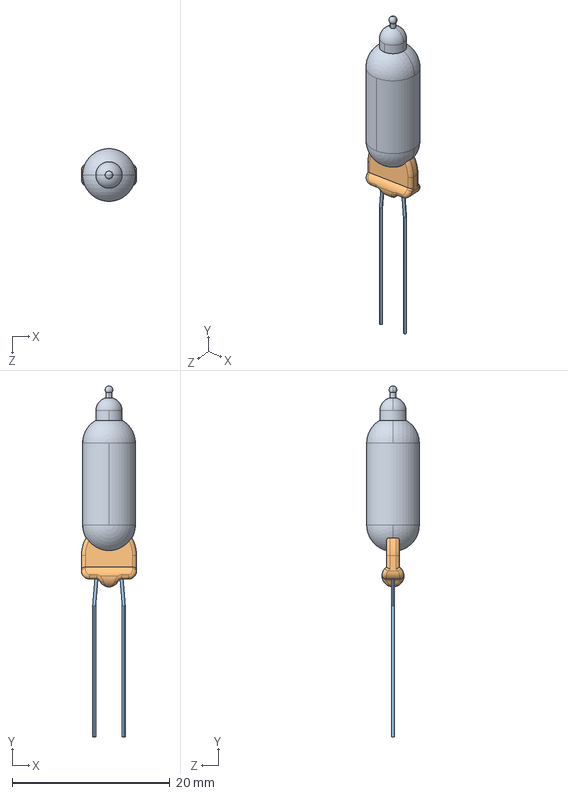
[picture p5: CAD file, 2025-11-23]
kicad_projects/omnixie_v0.2/3DModels/NX-SZP-IN3-v01.STEP
7.00 x 44.6 x 6.70 mm
NX-SZP-IN3-01-v01
NX-SZP-IN3-02-v01 x 2
NX-SZP-IN3-03-v01
NX-SZP-IN3-04-v01
NX-SZP-IN3-05-v01
NX-SZP-IN3-06-v01

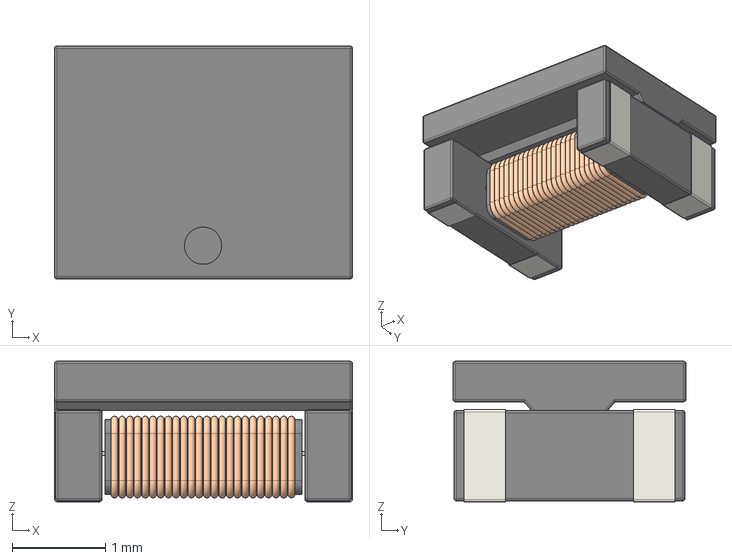
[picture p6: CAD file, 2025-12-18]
kicad_projects/omnixie_v0.2/3DModels/ATB322515-0110.stp
3.20 x 2.50 x 1.51 mm

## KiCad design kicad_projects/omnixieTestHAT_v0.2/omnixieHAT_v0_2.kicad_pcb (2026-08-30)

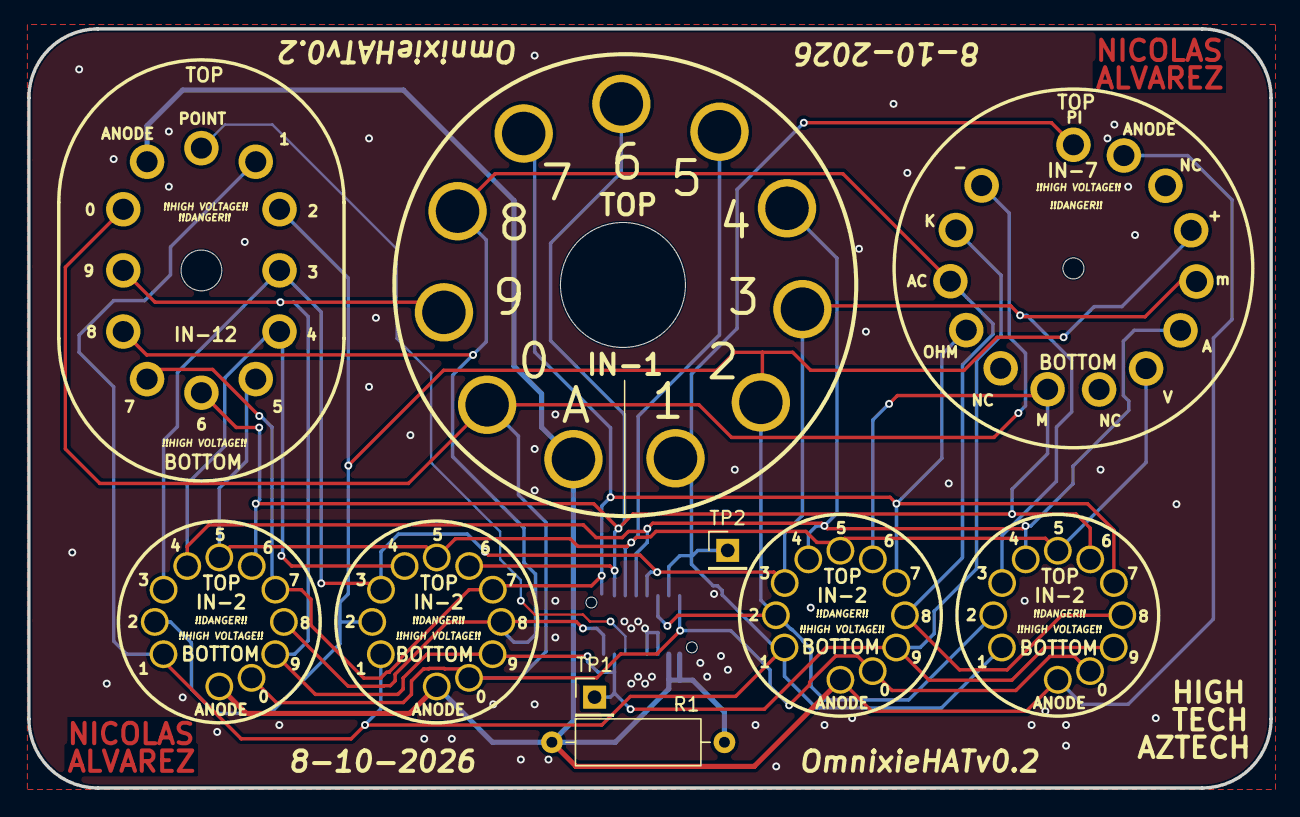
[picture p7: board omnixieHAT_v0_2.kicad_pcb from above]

Board: 2 copper layers, 91.4 x 55.9 mm, 11 parts (1 on the bottom side), 13 nets.

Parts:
J1: IL-WX-16PB-VF-B-E1000E; IL-WX-16PB-VF-B-E1000E-PINS
N1: IN-1_NIXIE_v1
N2, N5, N6, N7: IN-2
N3: IN-7
N4: IN-12BORIGINAL; IN-12A Nixie
R1: R; R_Axial_DIN0309_L9.0mm_D3.2mm_P12.70mm_Horizontal
TP1: 9; PinHeader_1x01_P2.54mm_Vertical
TP2: 1; PinHeader_1x01_P2.54mm_Vertical

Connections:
CATH0: J1.1, N1.0, N2.0, N3.14 (-), N4.0, N5.0, N6.0, N7.0
CATH1: J1.2, N1.1 (9), N2.1 (9), N3.1 (PI), N4.1, N5.1 (9), N6.1 (9), N7.1 (9), TP2.1 (1_1)
CATH2: J1.3, N1.2 (8), N2.2 (8), N3.4 (+), N4.2, N5.2 (8), N6.2 (8), N7.2 (8)
CATH3: J1.4, N1.3 (7), N2.3 (7), N3.5 (m), N4.3, N5.3 (7), N6.3 (7), N7.3 (7)
CATH4: J1.5, N1.4 (6), N2.4 (6), N3.6 (A), N4.4, N5.4 (6), N6.4 (6), N7.4 (6)
CATH5: J1.6, N1.5, N2.5, N3.7 (V), N4.5, N5.5, N6.5, N7.5
CATH6: J1.7, N1.6 (4), N2.6 (4), N3.9 (M), N4.6, N5.6 (4), N6.6 (4), N7.6 (4)
CATH7: J1.8, N1.7 (3), N2.7 (3), N3.11 (OHM), N4.7, N5.7 (3), N6.7 (3), N7.7 (3)
CATH8: J1.9, N1.8 (2), N2.8 (2), N3.12 (AC), N4.8, N5.8 (2), N6.8 (2), N7.8 (2)
CATH9: J1.10, N1.9 (1), N2.9 (1), N3.13 (K), N4.9, N5.9 (1), N6.9 (1), N7.9 (1), TP1.1 (1_1)
CATHDP: J1.11, N4.DP
GND: J1.13, J1.14
HIGHVOLTAGE: J1.15, J1.16, N1.A, N2.A, N3.2 (A), N4.A, N5.A, N6.A, N7.A, R1.1, R1.2

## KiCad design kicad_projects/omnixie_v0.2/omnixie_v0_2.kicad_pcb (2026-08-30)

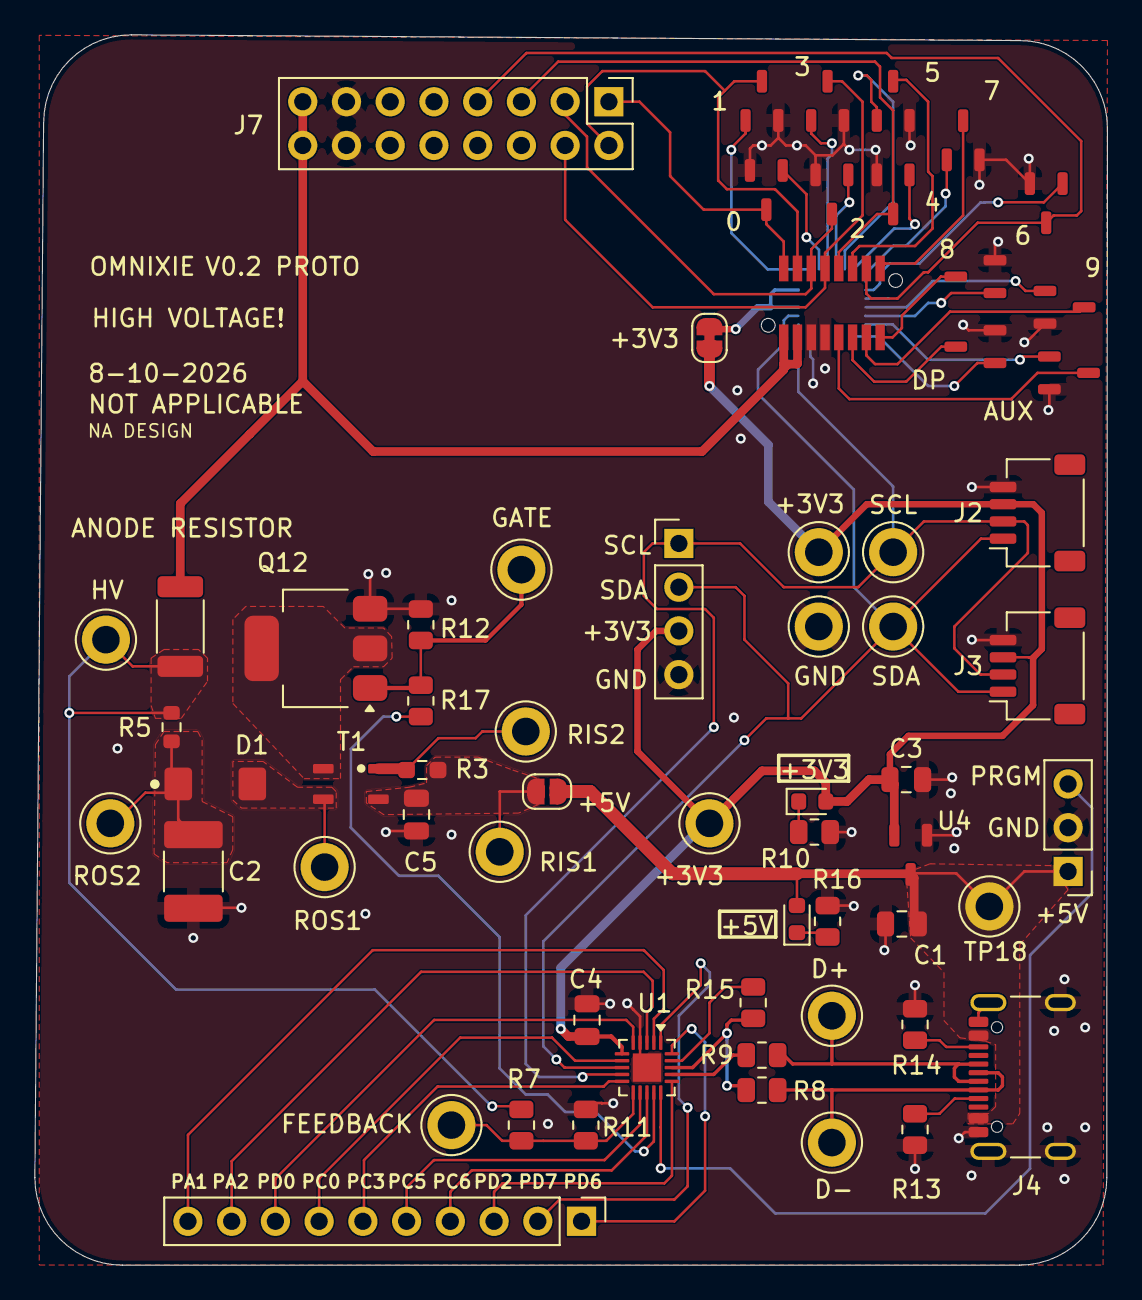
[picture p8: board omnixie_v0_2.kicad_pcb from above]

Board: 2 copper layers, 62.3 x 71.5 mm, 64 parts (1 on the bottom side), 60 nets.

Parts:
+3V3, +3V3#2: 5005; TestPoint_Keystone_5005-5009_Compact
+5V: GREEN; LED_0603_1608Metric
C1: 10uF; C_0805_2012Metric
C2: 0.22uF; C_1812_4532Metric_Pad1.57x3.40mm_HandSolder
C3, C4, C5: 1uF; C_0805_2012Metric
D1: SK3200AFL-TP; SK3200AFL
D3: GREEN; LED_0603_1608Metric
D+: 5005; TestPoint_Keystone_5005-5009_Compact
D-: 5005; TestPoint_Keystone_5005-5009_Compact
GND: 5005; TestPoint_Keystone_5005-5009_Compact
J1: Conn_01x10; PinHeader_1x10_P2.54mm_Vertical
J2, J3: SM04B-SRSS-TB; JST_SH_SM04B-SRSS-TB_1x04-1MP_P1.00mm_Horizontal
J4: USB4105-GF-A; USB_C_Receptacle_GCT_USB4105-xx-A_16P_TopMnt_Horizontal
J5: Conn_01x04; PinHeader_1x04_P2.54mm_Vertical
J6: Conn_01x02; PinHeader_1x03_P2.54mm_Vertical
J7: Conn_02x08_Counter_Clockwise; PinHeader_2x08_P2.54mm_Vertical
J8: IL-WX-16S-VF-B-E1000E; IL-WX-16S-VF-B-E1000E-SOCKET
JP4: SMT_THERM_JMP; SolderJumper-2_P1.3mm_Bridged_RoundedPad1.0x1.5mm
JP5: TH_THERM_JMP; SolderJumper-2_P1.3mm_Open_RoundedPad1.0x1.5mm
Q0, Q1, Q2, Q3, Q4, Q5, Q6, Q7, Q8, Q9, Q10, Q11: BSS123; SOT-23-3-NO_SILK
Q12: STN1NK60ZL; SOT-223-MiddlePinDrain
R3: 10m; R_0603_1608Metric_Pad0.98x0.95mm_HandSolder
R5: 10m; R_0603_1608Metric
R6: 15k; R_2010_5025Metric
R7: 100k; R_0805_2012Metric
R8, R9: 47; R_0805_2012Metric
R10, R16: 30K; R_0805_2012Metric
R11, R12: 1k; R_0805_2012Metric
R13, R14: 5.1k; R_0805_2012Metric
R15: 1.5k; R_0805_2012Metric
R17: JUMPER; R_0805_2012Metric
RIS1: 5005; TestPoint_Keystone_5005-5009_Compact
SCL: 5005; TestPoint_Keystone_5005-5009_Compact
SDA: 5005; TestPoint_Keystone_5005-5009_Compact
T1: ATB322515-0110; ATB322515
TP6, TP8, TP11, TP12, TP13, TP14, TP18: 5005; TestPoint_Keystone_5005-5009_Compact
U1: CH32V003F4U6; QFN-20-1EP_3x3mm_P0.4mm_EP1.65x1.65mm
U3: PI4IOE5V6416ZDEX; PI4IOE5V6416ZDEX-TQFN24
U4: XC6206P332MR; SOT-23-3-NO_SILK

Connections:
+3V3: +3V3.1 (1_1), +3V3#2.1 (1_1), C3.1, C4.1, D3.2 (A), J2.3, J3.3, J5.3, JP4.1 (A), U1.6 (VDD), U4.2 (VO)
+3V3_JUMP: JP4.2 (B), U3.21 (VDD_P), U3.23 (VDD_I2C)
+5V: +5V.2 (A), C1.1, J4.A4 (VBUS), J4.A9 (VBUS), J4.B4 (VBUS), J4.B9 (VBUS), J6.1, JP5.1 (A), TP18.1 (1_1), U4.3 (VI)
+5V_FLY: C5.1, JP5.2 (B), R3.2, RIS1.1 (1_1), T1.2
/<NO NET>: R3.1, T1.1, TP6.1 (1_1)
/CC1: J4.A5 (CC1), R13.1
/CC2: J4.B5 (CC2), R14.2
/D+_1: R9.2, U1.17 (PD3/A4/T2CH2/AETR/UCTS/T1CH4)
/D-_1: R8.2, R15.2, U1.18 (PD4/A7/UCK/T2CH1ETR/OPO/T1CH4ETR)
/D_1: D1.2 (A), T1.3, TP11.1 (1_1)
/D_2: C2.1, D1.1 (K), R5.2, TP8.1 (1_1)
/HV_1: R5.1, R6.2, R7.1, TP12.1 (1_1)
CATH0: J7.1, J8.1, Q0.3 (D)
CATH1: J7.2, J8.2, Q1.3 (D)
CATH2: J7.3, J8.3, Q2.3 (D)
CATH3: J7.4, J8.4, Q3.3 (D)
CATH4: J7.5, J8.5, Q4.3 (D)
CATH5: J8.6, Q5.3 (D)
CATH6: J7.7, J8.7, Q6.3 (D)
CATH7: J8.8, Q7.3 (D)
CATH8: J8.9, Q8.3 (D)
CATH9: J8.10, Q9.3 (D)
CATHAUX: J8.12, Q10.3 (D)
CATHDP: J8.11, Q11.3 (D)
D+: D+.1 (1_1), J4.A6 (D+), J4.B6 (D+), R9.1
D-: D-.1 (1_1), J4.A7 (D-), J4.B7 (D-), R8.1
DIG_0: Q0.1 (G), U3.2 (IO0_1)
DIG_1: Q1.1 (G), U3.1 (IO0_0)
DIG_2: Q2.1 (G), U3.4 (IO0_3)
DIG_3: Q3.1 (G), U3.3 (IO0_2)
DIG_4: Q4.1 (G), U3.6 (IO0_5)
DIG_5: Q5.1 (G), U3.5 (IO0_4)
DIG_6: Q6.1 (G), U3.8 (IO0_7)
DIG_7: Q7.1 (G), U3.7 (IO0_6)
DIG_8: Q8.1 (G), U3.11 (IO1_1)
DIG_9: Q9.1 (G), U3.10 (IO1_0)
DIG_AUX: Q10.1 (G), U3.12 (IO1_2)
DIG_DP: Q11.1 (G), U3.13 (IO1_3)
DPU: R15.1, U1.19 (PD5/A5/UTX/T2CH4/URX)
GND: C1.2, C2.2, C3.2, C4.2, C5.2, GND.1 (1_1), J2.4, J3.4, J4.A1 (GND), J4.A12 (GND), J4.B1 (GND), J4.B12 (GND), J4.SH (SHIELD), J5.4, J6.2, J7.13, J7.14, J8.13, J8.14, Q0.2 (S), Q1.2 (S), Q2.2 (S), Q3.2 (S), Q4.2 (S), Q5.2 (S), Q6.2 (S), Q7.2 (S), Q8.2 (S), Q9.2 (S), Q10.2 (S), Q11.2 (S), Q12.3 (S), R10.1, R11.2, R12.2, R13.2, R14.1, R16.1, U1.4 (VSS), U1.21 (GND), U3.9 (VSS), U3.18 (ADDR), U4.1 (GND)
HIGHVOLTAGE: J7.15, J7.16, J8.15, J8.16, R6.1
HV_FEEDBACK: R7.2, R11.1, TP13.1 (1_1), U1.11 (PC4/A2/T1CH4/MCO/T1CH1CH2N)
HV_SW: R17.1, U1.14 (PC7/MISO/T1CH2/T2CH2/URTS)
I2C_SCL: J2.2, J3.2, J5.1, SCL.1 (1_1), U1.9 (PC2/SCL/URTS/T1BKIN/AETR/T2CH2/T1ETR), U3.19 (SCL)
I2C_SDA: J2.1, J3.1, J5.2, SDA.1 (1_1), U1.8 (PC1/SDA/NSS/T2CH4/T2CH1ETR/T1BKIN/URX), U3.20 (SDA)
unnamed: +5V.1 (K), R16.2
unnamed: D3.1 (K), R10.2
unnamed: Q12.2 (D), T1.4
unnamed: Q12.1 (G), R12.1, R17.2, TP14.1 (1_1)
PA1: J1.10, U1.2 (PA1/OSCI/A1/T1CH2/OPN0)
PA2: J1.9, U1.3 (PA2/OSCO/A0/T1CH2N/OPP0/AETR2)
PC0: J1.7, U1.7 (PC0/T2CH3/UTX/NSS/T1CH3)
PC3: J1.6, U1.10 (PC3/T1CH3/T1CHIN/UCTS)
PC5: J1.5, U1.12 (PC5/SCK/T1ETR/T2CH1ETR/SCL/UCK/T1CH3)
PC6: J1.4, U1.13 (PC6/MOSI/T1CH1CH3/UCTS/SDA)
PD0: J1.8, U1.5 (PD0/T1CH1N/OPN1/SDA/UTX)
PD2: J1.3, U1.16 (PD2/A3/T1CH1/T2CH3/T1CH2N)
PD6: J1.1, U1.20 (PD6/A7/URX/T2CH3/UTX)
PD7: J1.2, U1.1 (PD7/NRST/T2CH4/OPP1/UCK)
PROGRAM: J6.3, U1.15 (PD1/SWIO/AETR/T1CH3/SCL/URX)

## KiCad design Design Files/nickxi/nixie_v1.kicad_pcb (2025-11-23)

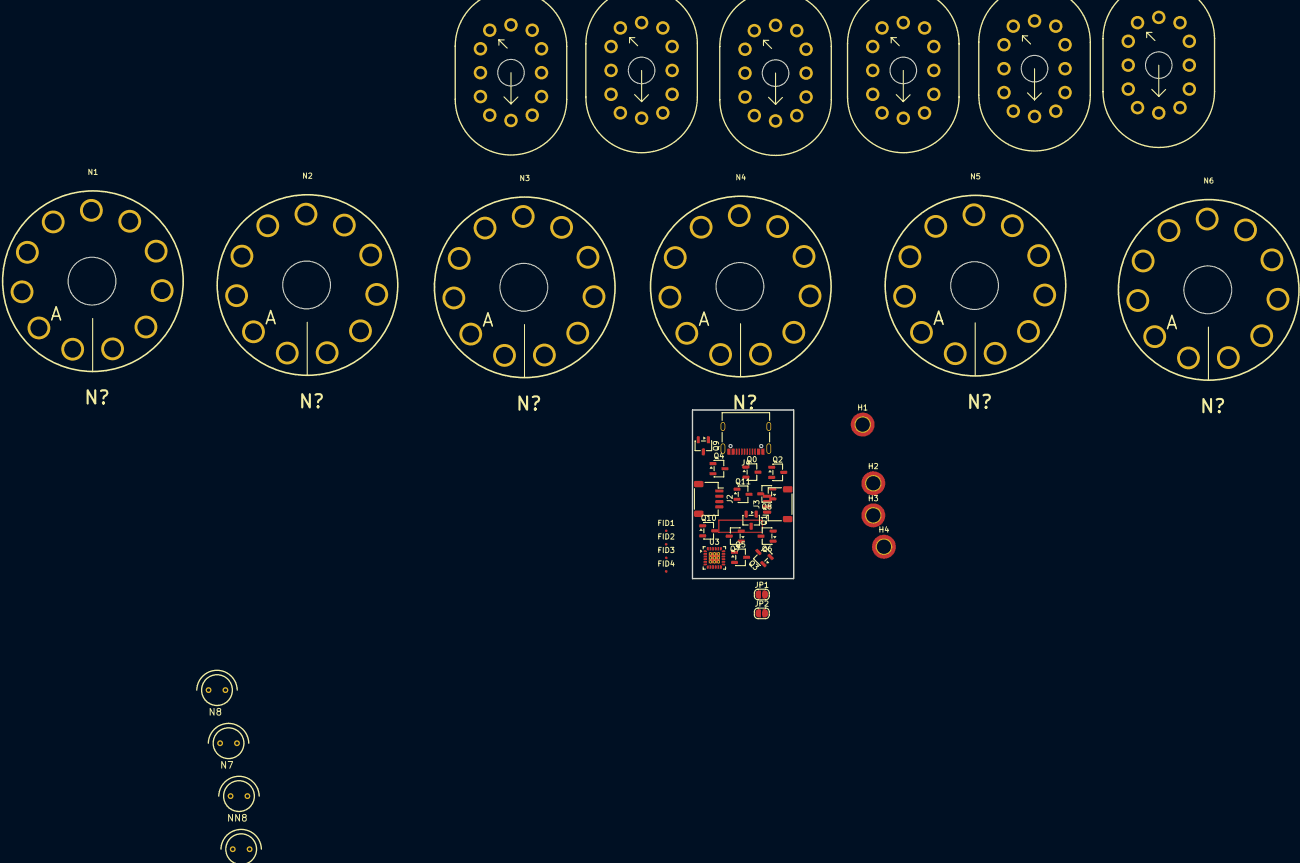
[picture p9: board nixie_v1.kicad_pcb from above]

Board: 2 copper layers, 43 parts (1 on the bottom side), 14 nets, no tracks yet.

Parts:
FID1, FID2, FID3, FID4: Fiducial; Fiducial_0.5mm_Mask1mm
H1, H2, H3, H4: MountingHole; MountingHole_2.7mm_M2.5_ISO7380_Pad_TopBottom
J2, J3: Conn_01x04; JST_SH_SM04B-SRSS-TB_1x04-1MP_P1.00mm_Horizontal
J4: USB_C_Receptacle_USB2.0_14P; USB_C_Receptacle_Palconn_UTC16-G
JP1, JP2: TH_THERM_JMP; SolderJumper-2_P1.3mm_Open_RoundedPad1.0x1.5mm
N1, N2, N3, N4, N5, N6: IN-1; IN-1_NIXIE_v1
N7, N8, N9: IN-3; nixies-us-IN-3
NN8: IN-3; nixies-us-IN-3
NX1, NX2, NX3, NX4, NX5, NX6: IN-12BORIGINAL; IN-12A Nixie
Q0, Q1, Q2, Q3, Q4, Q5, Q6, Q7, Q8, Q9, Q10, Q11: Q_NMOS; SOT-23-3
U1: CH32V003F4U6; QFN-20-1EP_3x3mm_P0.4mm_EP1.65x1.65mm
U3: TQFN-24-1EP_4x4mm_P0.5mm_EP2.1x2.1mm_ThermalVias

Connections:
CATH0: N1.0, N2.0, Q0.3 (D)
CATH1: N1.1, N2.1, NX1.1, Q1.3 (D)
CATH2: N1.2, N2.2, NX1.2, Q2.3 (D)
CATH3: N1.3, N2.3, NX1.3, Q3.3 (D)
CATH4: N1.4, N2.4, NX1.4, Q4.3 (D)
CATH5: N1.5, N2.5, NX1.5, Q5.3 (D)
CATH6: N1.6, N2.6, NX1.6, Q6.3 (D)
CATH7: N1.7, N2.7, NX1.7, Q7.3 (D)
CATH8: N1.8, N2.8, NX1.8, Q8.3 (D)
CATH9: N1.9, N2.9, NX1.9, Q9.3 (D)
GND: Q0.2 (S), Q1.2 (S), Q2.2 (S), Q3.2 (S), Q4.2 (S), Q5.2 (S), Q6.2 (S), Q7.2 (S), Q8.2 (S), Q9.2 (S), Q10.2 (S), Q11.2 (S), U1.4 (VSS), U1.21 (GND)
unnamed: J4.A1 (GND), J4.A12 (GND), J4.B1 (GND), J4.B12 (GND)
unnamed: J4.A4 (VBUS), J4.A9 (VBUS), J4.B4 (VBUS), J4.B9 (VBUS)
unnamed: JP1.2 (B), JP2.2 (B)

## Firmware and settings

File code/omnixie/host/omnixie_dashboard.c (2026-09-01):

// Host-side control panel for omnixie.c, talking to the CH32V003 over
// USB (rv003usb) rather than the WCH-Link SWIO debug-link mailbox 

//
//
// Protocol (must match omnixie.c):
//   8-byte buffer, byte[0] is always the HID report ID (0xaa).
//   Host -> device (hid_send_feature_report):
//     [1] = command: 0 = LED off, 1 = LED on, 2 = auto-blink
//     [2] = blink half-period, in 10ms ticks (only used for command 2)
//   Device -> host (hid_get_feature_report):
//     [1] = current LED state (0/1)
//     [2..5] = uptime in ms, little-endian
//     [6] = current command
//     [7] = current blink half-period, in 10ms ticks
//     [8..9] = PA1 ADC reading, little-endian, 10-bit (0-1023)

#include <stdio.h>
#include <stdlib.h>
#include <stdint.h>
#include <string.h>
#include <unistd.h>
#include <math.h>

#include "hidapi.c"

#define CNFG_IMPLEMENTATION
#define CNFGOGL
#include "rawdraw_sf.h"

#define USB_VENDOR_ID  0x1209
#define USB_PRODUCT_ID 0xd003
#define REPORT_ID      0xaa
#define MAILBOX_LEN    10
#define ADC_HISTORY    200 // ~4s of samples at the 20ms poll rate below
#define ADC_VREF       3.3f

enum { CMD_LED_OFF = 0, CMD_LED_ON = 1, CMD_LED_BLINK = 2 };

static int mouse_x, mouse_y, mouse_down;

void HandleKey( int keycode, int bDown ) { }
void HandleButton( int x, int y, int button, int bDown ) { mouse_x = x; mouse_y = y; mouse_down = bDown; }
void HandleMotion( int x, int y, int mask ) { mouse_x = x; mouse_y = y; }
int HandleDestroy() { return 0; }

typedef struct { int x0, y0, x1, y1; const char * label; } Button;

// Used when checking whether the cursor is within the bounds of the button
static int InButton( const Button * b, int x, int y )
{
	return x >= b->x0 && x < b->x1 && y >= b->y0 && y < b->y1;
}

static void DrawButton( const Button * b, int active )
{
	// Change color if active
	CNFGColor( active ? 0x40a040ff : 0x606060ff ); 
	CNFGTackRectangle( b->x0, b->y0, b->x1, b->y1 );
	CNFGColor( 0xffffffff );
	CNFGPenX = b->x0 + 8;
	CNFGPenY = b->y0 + (b->y1 - b->y0)/2 - 4;
	CNFGDrawText( b->label, 2 );
}

static void SendCommand( hid_device * hd, uint8_t cmd, uint8_t param )
{
	uint8_t buf[MAILBOX_LEN] = {0};
	buf[0] = REPORT_ID;
	buf[1] = cmd;
	buf[2] = param;
	int r = hid_send_feature_report( hd, buf, sizeof(buf) ); // TX
	if( r != sizeof(buf) )
		fprintf( stderr, "Warning: command send failed (%d)\n", r );
}

int main()
{
	CNFGSetup( "OMNIXIE USB Control Panel", 480, 420 );

	Button btn_off  = { 20, 60, 140, 100, "LED OFF" };
	Button btn_on   = { 160, 60, 280, 100, "LED ON" };
	Button btn_blink = { 300, 60, 420, 100, "BLINK" };
	Button btn_slower = { 300, 120, 360, 160, "-" }; // - 10ms
	Button btn_faster = { 380, 120, 440, 160, "+" }; // + 10ms

	uint8_t command = 0xff; // sentinel: no report received yet, doesn't match any real CMD_*
	uint8_t led_state = 0, period_ticks = 0;
	uint32_t uptime_ms = 0;
	uint16_t adc_value = 0;
	uint16_t adc_history[ADC_HISTORY] = {0};
	int adc_history_head = 0;
	int connected = 0;
	hid_device * hd = NULL;
	int was_down = 0;
	int frames_since_open_attempt = 0;

	while( CNFGHandleInput() )
	{
		CNFGBGColor = 0x101020ff;
		CNFGClearFrame();

		if( !hd && frames_since_open_attempt-- <= 0 )
		{
			connected = 0;
			hd = hid_open( USB_VENDOR_ID, USB_PRODUCT_ID, L"OMNIXIE00001" );
			frames_since_open_attempt = 50; // ~1s at the 20ms frame pacing below
		}

		if( hd )
		{
			uint8_t buf[MAILBOX_LEN];
			memset( buf, 0, sizeof(buf) );
			buf[0] = REPORT_ID;
			int r = hid_get_feature_report( hd, buf, sizeof(buf) ); // RX from MCU
			if( r >= MAILBOX_LEN )
			{
				connected = 1;
				led_state = buf[1];
				uptime_ms = (uint32_t)buf[2] | ((uint32_t)buf[3]<<8) | ((uint32_t)buf[4]<<16) | ((uint32_t)buf[5]<<24);
				command = buf[6];
				period_ticks = buf[7];
				adc_value = (uint16_t)buf[8] | ((uint16_t)buf[9]<<8);
				adc_history[adc_history_head] = adc_value;
				adc_history_head = (adc_history_head + 1) % ADC_HISTORY;
			}
			else
			{
				hid_close( hd );
				hd = NULL;
				connected = 0;
			}
		}

		int click = mouse_down && !was_down;
		was_down = mouse_down;

		if( click && hd )
		{
			if( InButton( &btn_off, mouse_x, mouse_y ) )
				SendCommand( hd, CMD_LED_OFF, 0 );
			else if( InButton( &btn_on, mouse_x, mouse_y ) )
				SendCommand( hd, CMD_LED_ON, 0 );
			else if( InButton( &btn_blink, mouse_x, mouse_y ) )
				SendCommand( hd, CMD_LED_BLINK, period_ticks ? period_ticks : 25 );
			else if( InButton( &btn_slower, mouse_x, mouse_y ) )
			{
				uint8_t np = period_ticks > 5 ? period_ticks - 5 : 5;
				SendCommand( hd, CMD_LED_BLINK, np );
			}
			else if( InButton( &btn_faster, mouse_x, mouse_y ) )
			{
				uint8_t np = period_ticks < 250 ? period_ticks + 5 : 250;
				SendCommand( hd, CMD_LED_BLINK, np );
			}
		}

		CNFGColor( 0xffffffff );
		CNFGPenX = 20; CNFGPenY = 15;
		CNFGDrawText( connected ? "Connected over USB" : "Waiting for device (VID 1209 / PID d003)...", 3 );

		DrawButton( &btn_off,  connected && command == CMD_LED_OFF && !led_state );
		DrawButton( &btn_on,   connected && command == CMD_LED_OFF && led_state );
		DrawButton( &btn_blink, connected && command == CMD_LED_BLINK );
		DrawButton( &btn_slower, 0 );
		DrawButton( &btn_faster, 0 );

		// Live LED indicator, reflecting what the device just reported.
		CNFGColor( led_state ? 0xffcc00ff : 0x333333ff );
		{
			int cx = 60, cy = 220, rad = 25;
			RDPoint poly[16];
			int i;
			for( i = 0; i < 16; i++ )
			{
				double a = i * 2 * 3.14159265 / 16;
				poly[i].x = cx + (int)(rad * cosf(a));
				poly[i].y = cy + (int)(rad * sinf(a));
			}
			CNFGTackPoly( poly, 16 );
		}

		char status[256];
		snprintf( status, sizeof(status), "command: %s   period: %dms   uptime: %.1fs",
			command == CMD_LED_BLINK ? "AUTO" : (led_state ? "ON" : "OFF"),
			period_ticks * 10,
			uptime_ms / 1000.0 );
		CNFGColor( 0xccccccff );
		CNFGPenX = 20; CNFGPenY = 260;
		CNFGDrawText( status, 2 );

		{
			char adc_label[64];
			snprintf( adc_label, sizeof(adc_label), "ADC (PA1): %4d  (%.2fV)", adc_value, adc_value / 1023.0f * ADC_VREF );
			CNFGColor( 0xccccccff );
			CNFGPenX = 20; CNFGPenY = 300;
			CNFGDrawText( adc_label, 2 );

			int gx0 = 20, gy0 = 330, gx1 = 460, gy1 = 400;
			CNFGColor( 0x404040ff );
			CNFGDrawBox( gx0, gy0, gx1, gy1 );

			CNFGColor( 0x40c0ffff );
			int i;
			int px = 0, py = 0;
			for( i = 0; i < ADC_HISTORY; i++ )
			{
				uint16_t sample = adc_history[(adc_history_head + i) % ADC_HISTORY];
				int x = gx0 + i * (gx1 - gx0) / (ADC_HISTORY - 1);
				int y = gy1 - (int)( (sample / 1023.0f) * (gy1 - gy0) );
				if( i > 0 ) CNFGTackSegment( px, py, x, y );
				px = x; py = y;
			}
		}

		CNFGSwapBuffers();
		usleep( 20000 ); // ~50Hz poll; feature reports are control transfers, no need to hammer them
	}

	if( hd ) hid_close( hd );
	return 0;
}

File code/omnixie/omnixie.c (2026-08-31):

// LED blink demo, now driven live over USB (rv003usb)

#include "ch32fun.h"
#include <string.h>
#include "rv003usb.h"

#define PIN_LED 		PD6
#define PIN_ADC_INPUT	PA1
#define ADC_INPUT		1

enum {
	CMD_LED_OFF      = 0,
	CMD_LED_ON       = 1,
	CMD_LED_BLINK = 2,
};

// Report ID 0xaa, 8 bytes total (1 ID byte + 7 data bytes), matching
// HID_REPORT_COUNT(7) in usb_config.h. This one report is reused for both
// hid_send_feature_report (host->device command) and
// hid_get_feature_report (device->host status).
#define MAILBOX_LEN 8
#define MAILBOX_REPORT_ID 0xaa

static volatile uint8_t mailbox_in[MAILBOX_LEN];  // host -> device, filled by usb_handle_user_data
static uint8_t mailbox_out[MAILBOX_LEN];          // device -> host, filled on demand in usb_handle_hid_get_report_start

static volatile uint8_t command = CMD_LED_BLINK;
static volatile uint8_t blink_half_period_ticks = 25; // *10ms => 250ms, matches the original blink example
static volatile uint8_t led_state = 0;
static volatile uint32_t uptime_ms = 0;

static void SetLed( int on )
{
	// led_state = on ? 1 : 0;
	funDigitalWrite( PIN_LED, on ? FUN_HIGH : FUN_LOW );
}

static void ApplyCommand( const uint8_t * cmd )
{
	uint8_t new_command = cmd[1];
	if( new_command == CMD_LED_BLINK )
	{
		if( cmd[2] ) blink_half_period_ticks = cmd[2];
		command = CMD_LED_BLINK;
	}
	else
	{
		command = CMD_LED_OFF; // parked; SetLed below drives the actual pin
		SetLed( new_command == CMD_LED_ON ); // Why is this CMD_LED_ON instead of CMD_LED_OFF I thought the logic would be different here?
	}
}

int main()
{
	SystemInit();

	// where are these fun functions defined?
	funGpioInitAll(); // what exactly does this do? what does it inialitze all GPIO to? what speed? what config? pull up? pull down? etc?
	

	//initialize all ADC?
	// just initialize what's neceassry for PA1?

	//why is this called funPincommand and not funPinMode? I would have thought it would be mode not command
	funPincommand( PIN_LED, GPIO_Speed_10MHz | GPIO_CNF_OUT_PP ); // is GPIO_CNF_OUT_PP push-pull?

	// funPinMode( PA1, GPIO_CFGLR_OUT_10Mhz_PP );
	// funAnalogRead( 0 );
	

	Delay_Ms(100); // Ensures USB re-enumeration after bootloader or reset; spec demands >2.5us (TDDIS)
	usb_setup();

	uint32_t last_toggle = 0;

	while(1)
	{
		Delay_Ms(10);
		uptime_ms += 10;

		// What is this if-statement doing?
		if( command == CMD_LED_BLINK &&
		    uptime_ms - last_toggle >= (uint32_t)blink_half_period_ticks * 10 )
		{
			last_toggle = uptime_ms;
			SetLed( !led_state );
		}
	}
}

// We don't use the interrupt-IN endpoint for anything; everything rides on
// control (feature report) transfers, so just ack it if the host ever polls it.

// What is this typically used for though?
// do we need this definition and the other one ?
void usb_handle_user_in_request( struct usb_endpoint * e, uint8_t * scratchpad, int endp, uint32_t sendtok, struct rv003usb_internal * ist )
{
	if( endp )
		usb_send_empty( sendtok );
}

// hid_get_feature_report: build the live status snapshot on demand.
// TX
void usb_handle_hid_get_report_start( struct usb_endpoint * e, int reqLen, uint32_t lValueLSBIndexMSB )
{
	uint32_t now = uptime_ms;

	mailbox_out[0] = MAILBOX_REPORT_ID;
	mailbox_out[1] = led_state;
	mailbox_out[2] = now & 0xff;
	mailbox_out[3] = (now>>8) & 0xff;
	mailbox_out[4] = (now>>16) & 0xff;
	mailbox_out[5] = (now>>24) & 0xff;
	mailbox_out[6] = command;
	mailbox_out[7] = blink_half_period_ticks;

	if( reqLen > MAILBOX_LEN ) reqLen = MAILBOX_LEN; // Why is this needed?
	e->opaque = mailbox_out; // Why is it called opaque and is mailbox_out handled somewhere in main?
	e->max_len = reqLen;
}

// hid_send_feature_report: just declare the expected length; the actual
// bytes land via usb_handle_user_data below (mirrors demo_hidapi's scratchpad).
void usb_handle_hid_set_report_start( struct usb_endpoint * e, int reqLen, uint32_t lValueLSBIndexMSB )
{
	if( reqLen > MAILBOX_LEN ) reqLen = MAILBOX_LEN;
	e->max_len = reqLen;
}

// RX
void usb_handle_user_data( struct usb_endpoint * e, int current_endpoint, uint8_t * data, int len, struct rv003usb_internal * ist )
{
	int offset = e->count<<3;
	int torx = e->max_len - offset;
	if( torx > len ) torx = len;
	if( torx > 0 )
	{
		memcpy( (uint8_t*)mailbox_in + offset, data, torx );
		e->count++;
		if( ( e->count << 3 ) >= e->max_len )
		{
			ApplyCommand( (const uint8_t*)mailbox_in );
		}
	}
}

void usb_handle_other_control_message( struct usb_endpoint * e, struct usb_urb * s, struct rv003usb_internal * ist )
{
	// Nothing else expected; ignore.
}

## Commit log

2025-11-23 Adding files:
    [NX-SZP-IN3-v01.STEP, nixie_v1.kicad_pcb, nixie_v1.kicad_sch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]
2025-12-04 commiting last work i did
    [NX-SZP-IN3-v01.STEP, OMNIXIE.xlsx, OMNIXIE_v1.kicad_pcb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]
2025-12-08 changed folder names, started bom
    [NX-SZP-IN3-v01.STEP, OMNIXIE.xlsx, omnixie_v1.kicad_pcb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]
2025-12-18 component selection nearly done
    [NX-SZP-IN3-v01.STEP, OMNIXIE.xlsx, OMNIXIE_sheets.xlsx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]
2025-12-18 component placement commencing
    [ATB322515-0110.stp, OMNIXIE_sheets.xlsx, SM04B-SRSS-TB.STEP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]
2025-12-18 more component placement
    [omnixie_v1.kicad_pcb, omnixie_v1.kicad_sch]
2025-12-25 reworking the board. Its a prototype not production ready
    [OMNIXIE_sheets.xlsx, omnixie_v1.kicad_pcb, omnixie_v1.kicad_sch]
2025-12-25 new component placement pretty much done
    [omnixie_v1.kicad_pcb, omnixie_v1.kicad_sch]
2025-12-28 home from christmas in vegas
    [OMNIXIE_sheets.xlsx, omnixie_v1.kicad_pcb, omnixie_v1.kicad_sch]
2026-01-10 separated proto from production version with actual footprints
    [ATB322515-0110.stp, IN-12 Nixie Tube.STEP, NX-SZP-IN3-v01.STEP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]
2026-01-12 p much done, no nixie hat board though
    [OMNIXIE_sheets.xlsx, omnixie_v1.kicad_pcb, omnixie_v1.kicad_sch]
2026-03-26 remaining files i forgor
    [ATB322515-0110.stp, IN-12 Nixie Tube.STEP, IN_12_omnixie_hat_v1.kicad_sch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]
2026-06-06 removed unneccesary stuff
    [ATB322515-0110.stp, IN-12 Nixie Tube.STEP, NX-SZP-IN3-v01.STEP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]
2026-07-04 new folders for next versions
    [omnixieHAT_v0_1.kicad_pcb, omnixieHAT_v0_1.kicad_sch, omnixieHAT_v0_2.kicad_pcb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]
2026-07-16 redlines almost done, new layout commencing
    [OMNIXIE_sheets.ods, OMNIXIE_sheets.xlsx, omnixieHAT_v0_2.kicad_sch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]
2026-08-30 board bringup starting now
    [OMNIXIE_sheets.ods, omnixieHAT_v0_2.kicad_pcb, omnixieHAT_v0_2.kicad_sch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]
2026-09-01 raw draw works, beginning high voltage PID control
    [OMNIXIE_sheets.ods]
2026-09-01 added old pid files
